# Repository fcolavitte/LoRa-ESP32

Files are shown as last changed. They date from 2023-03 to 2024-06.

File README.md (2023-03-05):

# LoRa-ESP32
Proyecto de comunicación unidireccional de USB a LoRa para pruebas de comunicación con satelites LEO para la empresa Satellogic.
El dispositivo toma datos por Wi-Fi y USB y envía mensajes por módulo LoRa E22 a satélites LEO.

El proyecto cuenta con una interfaz de usuario por USB con un menu interactivo por medio de los números del teclado.
La interfaz USB también admite comandos específicos.

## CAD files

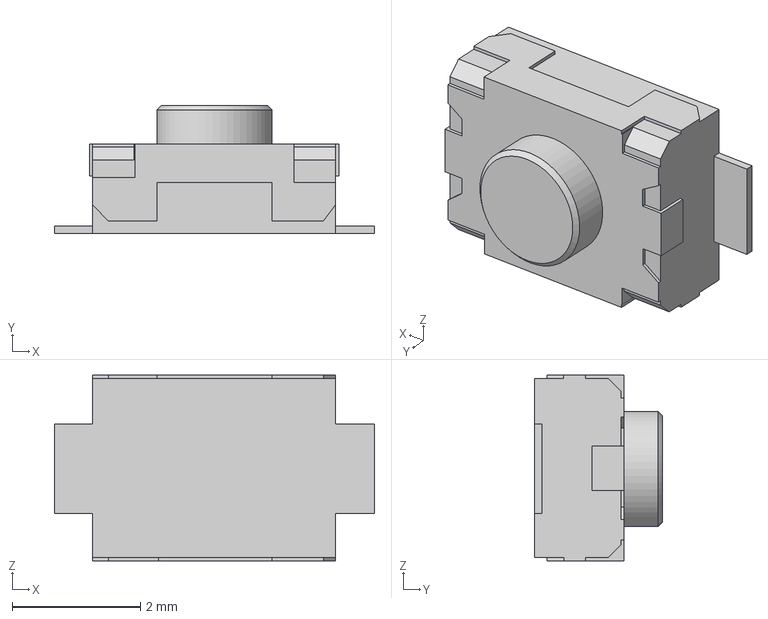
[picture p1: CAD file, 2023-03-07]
Hardware/PCB_Satellogic_2/Componentes STP/smd push button.step
5.00 x 2.00 x 2.90 mm

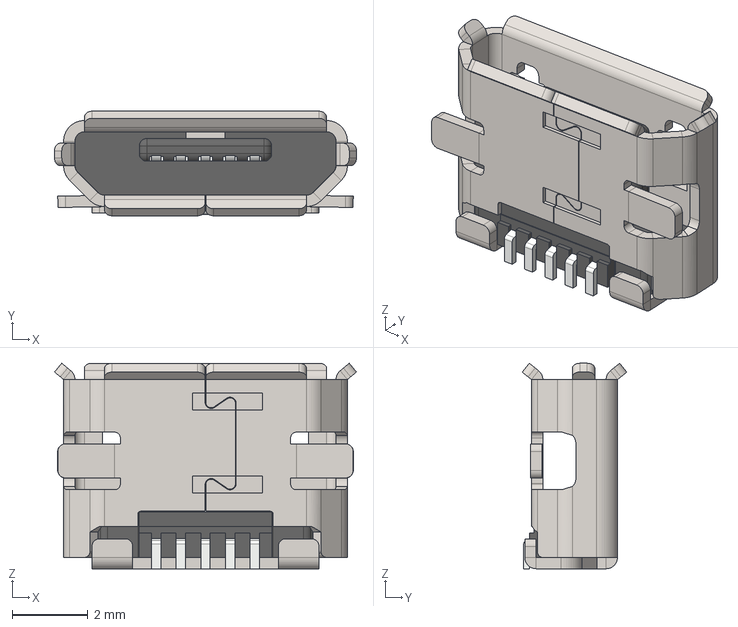
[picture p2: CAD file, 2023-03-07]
Hardware/PCB_Satellogic_2/Componentes STP/micro_USB.STEP
7.98 x 2.76 x 5.43 mm

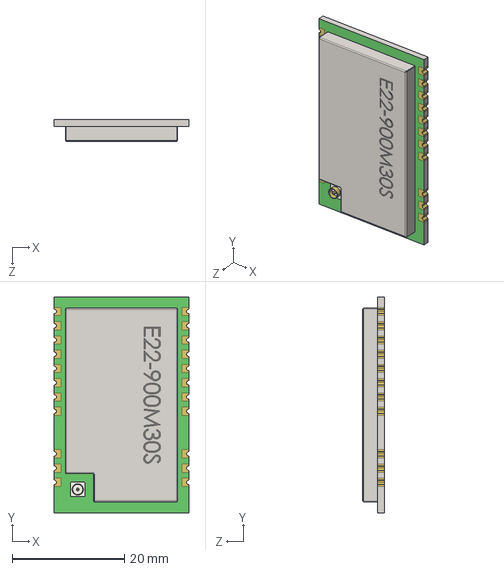
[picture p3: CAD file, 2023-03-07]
Hardware/PCB_Satellogic_2/Componentes STP/E22-900M30S.STEP
24.0 x 38.5 x 3.88 mm

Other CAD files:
Hardware/PCB_Satellogic_2/Componentes STP/E22-900M30S.SLDPRT

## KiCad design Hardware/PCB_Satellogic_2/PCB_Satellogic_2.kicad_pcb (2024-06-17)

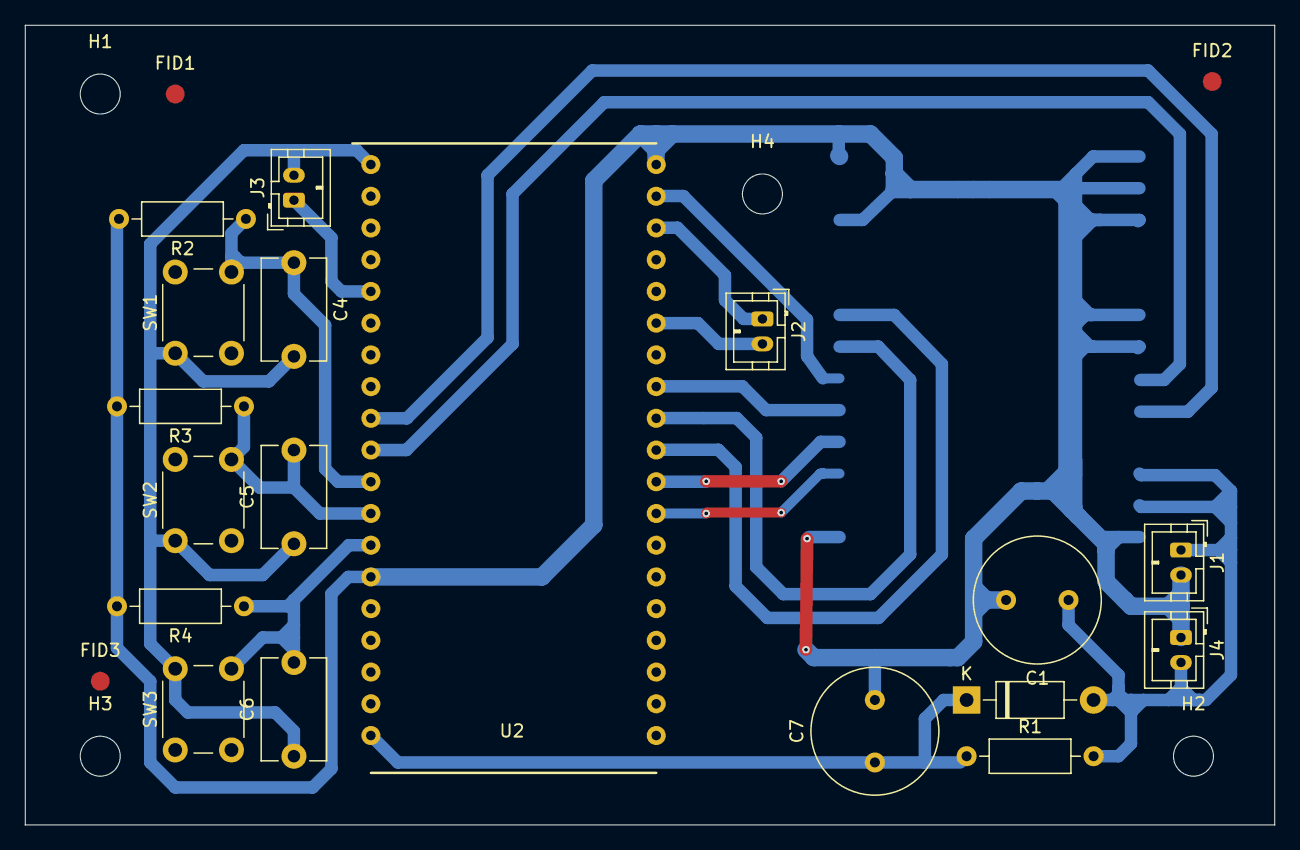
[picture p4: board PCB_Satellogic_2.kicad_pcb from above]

Board: 2 copper layers, 100.0 x 64.0 mm, 26 parts (1 on the bottom side), 18 nets.

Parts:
C1: 470uF; C_Radial_D10.0mm_H16.0mm_P5.00mm
C4, C5, C6: 10nF; C_Disc_D8.0mm_W5.0mm_P7.50mm
C7: 4.7uF; C_Radial_D10.0mm_H16.0mm_P5.00mm
D1: 1N5819; D_DO-41_SOD81_P10.16mm_Horizontal
FID1, FID2, FID3: Fiducial; Fiducial_1.5mm_Mask3mm
H1, H2, H3, H4: MountingHole; MountingHole_3.2mm_M3
J1: 5V_out; JST_PH_B2B-PH-K_1x02_P2.00mm_Vertical
J2: I2C; JST_PH_B2B-PH-K_1x02_P2.00mm_Vertical
J3: ADC; JST_PH_B2B-PH-K_1x02_P2.00mm_Vertical
J4: 5V_in; JST_PH_B2B-PH-K_1x02_P2.00mm_Vertical
R1: 100R; R_Axial_DIN0207_L6.3mm_D2.5mm_P10.16mm_Horizontal
R2, R3, R4: 2k2; R_Axial_DIN0207_L6.3mm_D2.5mm_P10.16mm_Horizontal
SW1: SetRXMode; SW_PUSH_6mm_H4.3mm
SW2: TX; SW_PUSH_6mm_H4.3mm
SW3: SetWiFiMode; SW_PUSH_6mm_H4.3mm
U1: E22-900M30S_LoRa; E22-900M30S_LoRa_smd
U2: Node-MCU_ESP32_38PINES; Node-MCU_ESP32_38PINES_THT_offset

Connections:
/3v3: C4.2, C5.1, C6.1, J3.2, SW1.1, SW2.1, SW3.1, U2.1 (3.3V)
/5V: C1.1, D1.2 (A), J1.1, J4.2, R1.2, U1.9 (Vcc), U1.10 (Vcc)
/ADC: J3.1, U2.5 (GPIO34)
/BUSY: U1.14 (BUSY), U2.27 (Rx2-GPIO16)
/MISO: U1.16 (MISO), U2.31 (MISO-GPIO19)
/MOSI: U1.17 (MOSI), U2.37 (MOSI-GPIO23)
/NSS: U1.19 (NSS), U2.29 (CS0-GPIO5)
/RST_E22: U1.15 (NRST), U2.28 (Tx2-GPIO17)
/RXEN: U1.6 (RXEN), U2.10 (GPIO26)
/SCK: U1.18 (SCK), U2.30 (CLK-GPIO18)
/SCL: J2.1, U2.36 (GPIO22)
/SDA: J2.2, U2.33 (GPIO21)
/SetRxMode: C4.1, R2.1, SW1.2, U2.11 (GPIO27)
/SetWiFiMode: C6.2, R4.1, SW3.2, U2.13 (GPIO12)
/TX: C5.2, R3.1, SW2.2, U2.12 (GPIO14)
/TXEN: U1.7 (TXEN), U2.9 (GPIO25)
GND: C1.2, C7.2, J1.2, J4.1, R2.2, R3.2, R4.2, U1.1 (GND), U1.2 (GND), U1.3 (GND), U1.4 (GND), U1.5 (GND), U1.11 (GND), U1.12 (GND), U1.20 (GND), U1.22 (GND), U2.14 (GND), U2.38 (GND)
unnamed: C7.1, D1.1 (K), R1.1, U2.19 (Vin)

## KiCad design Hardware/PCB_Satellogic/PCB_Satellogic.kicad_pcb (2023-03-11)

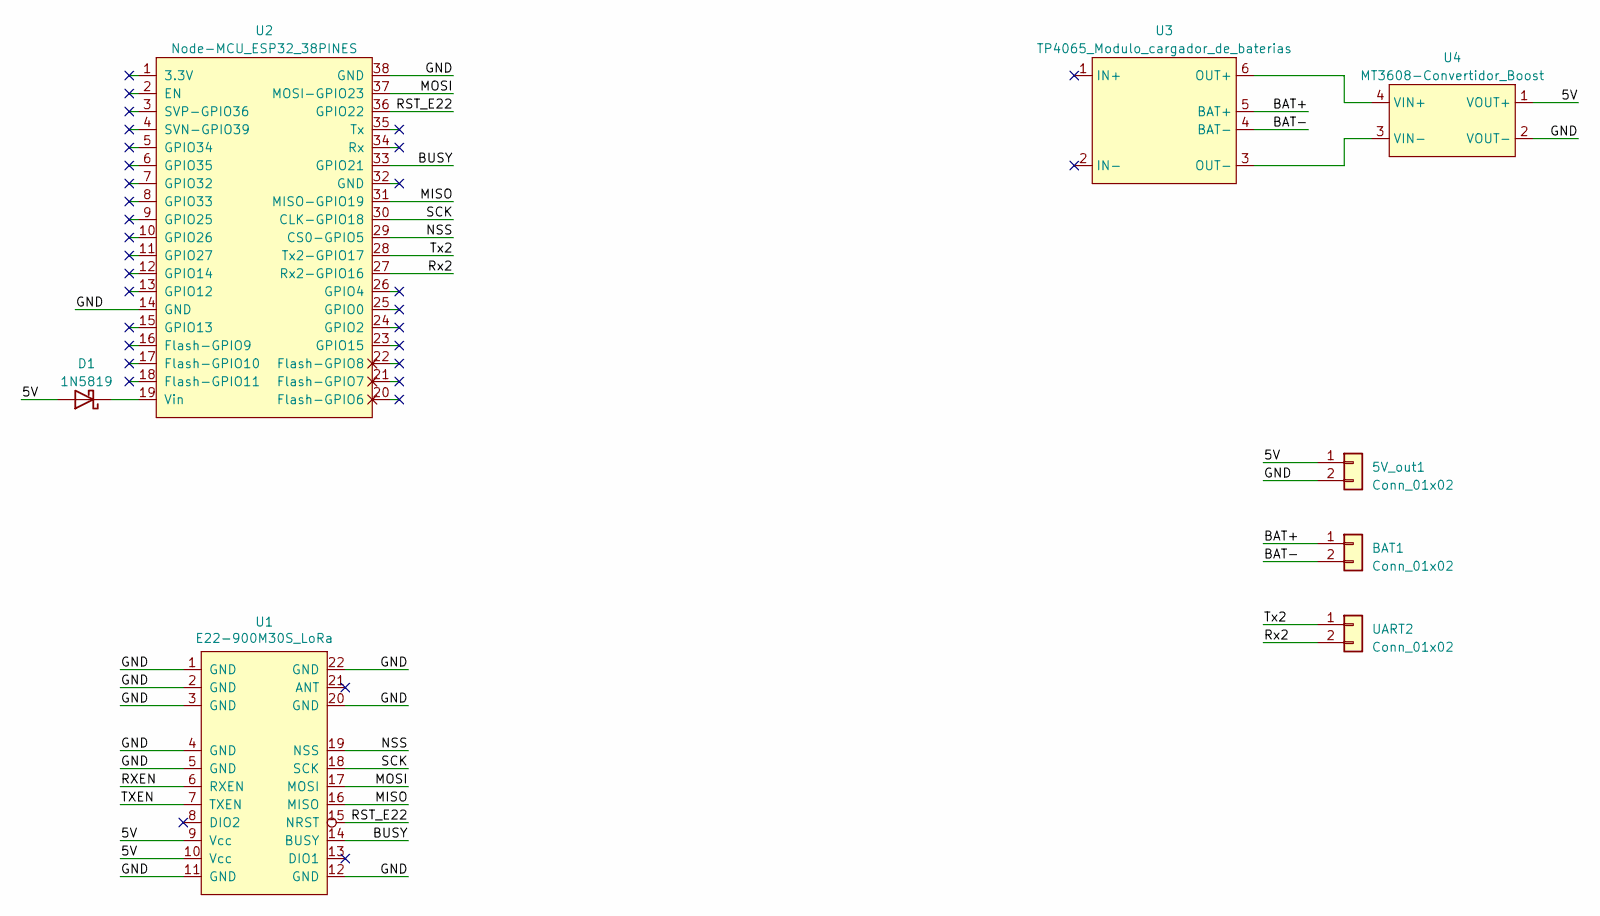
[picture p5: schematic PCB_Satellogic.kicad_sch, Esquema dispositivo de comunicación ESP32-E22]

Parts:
5V_out1: Conn_01x02; JST_PH_B2B-PH-K_1x02_P2.00mm_Vertical
BAT1: Conn_01x02; JST_PH_B2B-PH-K_1x02_P2.00mm_Vertical
D1: 1N5819; D_DO-41_SOD81_P10.16mm_Horizontal
U1: E22-900M30S_LoRa; E22-900M30S_LoRa_smd
U2: Node-MCU_ESP32_38PINES; Node-MCU_ESP32_38PINES_THT_offset
U3: TP4065_Modulo_cargador_de_baterias; TP4056 - Módulo de carga de batería
U4: MT3608-Convertidor_Boost
UART2: Conn_01x02; JST_PH_B2B-PH-K_1x02_P2.00mm_Vertical

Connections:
/5V: 5V_out1.1, D1.2 (A), U1.9 (Vcc), U1.10 (Vcc), U4.1 (VOUT+)
/BAT+: BAT1.1, U3.5 (BAT+)
/BAT-: BAT1.2, U3.4 (BAT-)
/BUSY: U1.14 (BUSY), U2.33 (GPIO21)
/GND: 5V_out1.2, U1.1 (GND), U1.2 (GND), U1.3 (GND), U1.4 (GND), U1.5 (GND), U1.11 (GND), U1.12 (GND), U1.20 (GND), U1.22 (GND), U2.14 (GND), U2.38 (GND), U4.2 (VOUT-)
/MISO: U1.16 (MISO), U2.31 (MISO-GPIO19)
/MOSI: U1.17 (MOSI), U2.37 (MOSI-GPIO23)
/NSS: U1.19 (NSS), U2.29 (CS0-GPIO5)
/RST_E22: U1.15 (NRST), U2.36 (GPIO22)
/RXEN: U1.6 (RXEN)
/Rx2: U2.27 (Rx2-GPIO16), UART2.2
/SCK: U1.18 (SCK), U2.30 (CLK-GPIO18)
/TXEN: U1.7 (TXEN)
/Tx2: U2.28 (Tx2-GPIO17), UART2.1
unnamed: D1.1 (K), U2.19 (Vin)
unnamed: U3.6 (OUT+), U4.4 (VIN+)
unnamed: U3.3 (OUT-), U4.3 (VIN-)

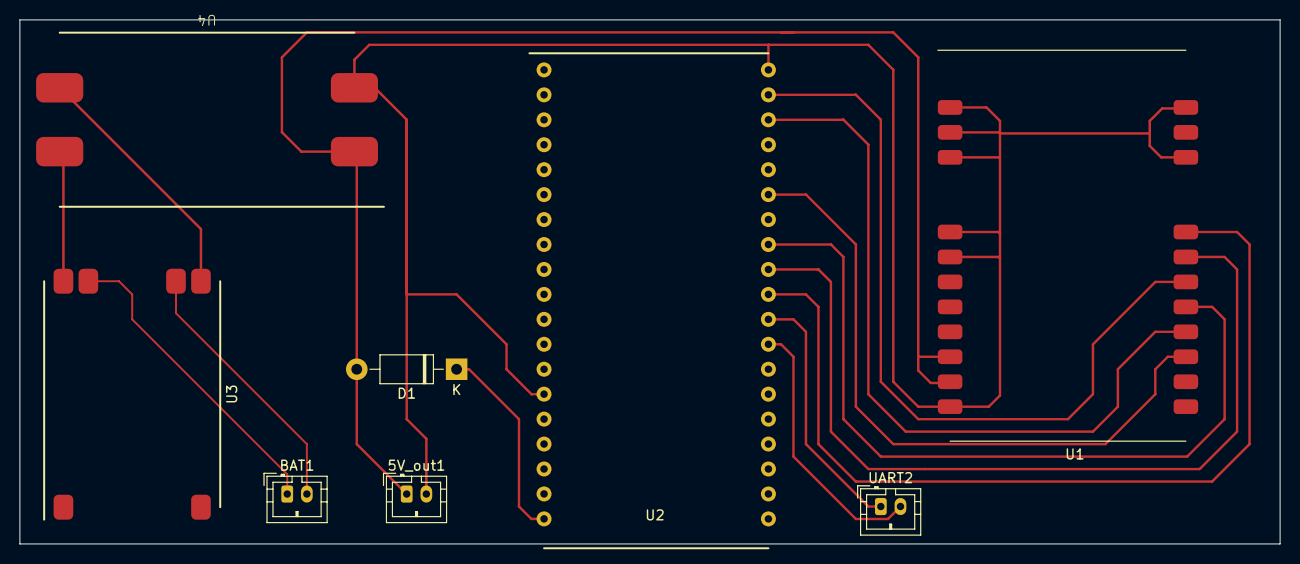
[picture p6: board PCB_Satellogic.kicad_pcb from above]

Board: 2 copper layers, 128.3 x 53.3 mm, 8 parts (0 on the bottom side), 15 nets.

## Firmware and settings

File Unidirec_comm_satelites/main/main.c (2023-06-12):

/*
 * @file   : main.c
 * @date   : Feb 17, 2023
 * @author : Colavitte Facundo G. <facundocolavitte@gmail.com>
 * @version	v1.0.0
 */

/********************** inclusions *******************************************/

#include "MEF.h"
#include "API_E22.h"
#include <freertos/FreeRTOS.h>
#include <freertos/task.h>
#include "E22_test_.h"

/********************** macros and definitions *******************************/

#define test_E22 0

/********************** internal data declaration ****************************/

/********************** internal functions declaration ***********************/

/********************** internal data definition *****************************/

/********************** external data definition *****************************/

/********************** internal functions definition ************************/

/********************** external functions definition ************************/

#if test_E22 == 0
void app_main(void) {
	driver_E22_init();
	start_MEF();
	while(1){
		update_MEF();
        vTaskDelay(10/ portTICK_PERIOD_MS);
	}
}
#endif






#if test_E22 == 1

void app_main(void) {
	start_MEF();
	driver_E22_init();

	while(1){
		/* Test Driver E22 */
		test_driver_E22_read_write_buffer_1byte();
	    test_driver_E22_read_write_buffer_2bytes();
        vTaskDelay(10000/ portTICK_PERIOD_MS);
	}
}
#endif

/********************** end of file ******************************************/

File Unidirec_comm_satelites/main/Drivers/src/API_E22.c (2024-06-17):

/*
 * @file   : API_E22.c
 * @date   : Mar 11, 2023
 * @author : Colavitte Facundo G. <facundocolavitte@gmail.com>
 * @version	v1.0.0
 */

#include "API_E22.h"
#include <stdint.h>
#include <stdbool.h>
#include <freertos/FreeRTOS.h>
#include <freertos/task.h>
#include <string.h>

/********************** inclusions *******************************************/

/********************** macros and definitions *******************************/

/********************** internal data declaration ****************************/

struct config_E22_s{
	uint16_t PreambleLength;
	bool Header_is_fixed_length;
	uint32_t frec_deseada_MHz;
};
struct config_E22_s config_E22 = {
		.PreambleLength = 12,
		.Header_is_fixed_length = 1,
		.frec_deseada_MHz = 915
};

/********************** internal functions declaration ***********************/

/********************** external functions declaration ***********************/

extern void driver_HAL_spi_init(void);
extern uint8_t driver_HAL_transaction(uint8_t *tx_buffer, uint8_t tx_length, uint8_t *rx_buffer, uint8_t rx_length);
extern void driver_HAL_gpio_init(uint8_t GPIO_num, bool GPIO_is_input);
extern void driver_HAL_GPIO_write(uint8_t GPIO, bool state);
extern bool driver_HAL_GPIO_read(uint8_t GPIO);
extern void driver_HAL_set_eneable_transaction_view(bool eneable);
extern bool driver_HAL_get_eneable_transaction_view(void);

/********************** internal data definition *****************************/

/********************** external data definition *****************************/

/********************** internal functions definition ************************/

/********************** external functions definition ************************/

void driver_E22_init(void) {
	driver_HAL_spi_init();
	driver_HAL_gpio_init(GPIO_E22_BUSY, INPUT);
	driver_HAL_gpio_init(GPIO_E22_NRST, OUTPUT);
	driver_HAL_gpio_init(GPIO_TX_ENABLE, OUTPUT);
	driver_HAL_gpio_init(GPIO_RX_ENABLE, OUTPUT);

	/* Cargar estados iniciales de los pines */
	driver_HAL_GPIO_write(GPIO_E22_NRST, HIGH);
	driver_HAL_GPIO_write(GPIO_TX_ENABLE, LOW);
	driver_HAL_GPIO_write(GPIO_RX_ENABLE, LOW);
}


void driver_E22_reset(void) {
	driver_HAL_GPIO_write(GPIO_E22_NRST, LOW);
    vTaskDelay(100);
	driver_HAL_GPIO_write(GPIO_E22_NRST, HIGH);
    vTaskDelay(100);
	driver_E22_set_standBy();
}


void driver_E22_write_in_buffer(uint8_t offset, uint8_t* tx_buffer, uint8_t tx_length) {
	if(MAX_SIZE_SPI_BUFFERS - 2 < tx_length) {
		tx_length = MAX_SIZE_SPI_BUFFERS - 2;
	}
	if(driver_HAL_GPIO_read(GPIO_E22_BUSY)) {
		vTaskDelay(1);
	}
	uint8_t MOSI_buffer[MAX_SIZE_SPI_BUFFERS] = {};
	MOSI_buffer[0] = OPCODE_WRITEBUFFER;
	MOSI_buffer[1] = offset;
	memcpy(&(MOSI_buffer[2]), tx_buffer, tx_length);
	driver_HAL_transaction(MOSI_buffer, tx_length+2, NULL, 0);
    vTaskDelay(1);
}


void driver_E22_read_from_buffer(uint8_t offset, uint8_t* rx_buffer, uint8_t rx_length) {
	if(MAX_SIZE_SPI_BUFFERS - 3 < rx_length) {
		rx_length = MAX_SIZE_SPI_BUFFERS - 3;
	}
	if(driver_HAL_GPIO_read(GPIO_E22_BUSY)) {
		vTaskDelay(1);
	}
	uint8_t MOSI_buffer[MAX_SIZE_SPI_BUFFERS] = {};
	MOSI_buffer[0] = OPCODE_READBUFFER;
	MOSI_buffer[1] = offset;
	MOSI_buffer[2] = NOP;
	driver_HAL_transaction(MOSI_buffer, 3, rx_buffer, rx_length);
    vTaskDelay(1);
}

void driver_E22_clear_buffer(uint8_t offset, uint8_t length, uint8_t characters) {
	if(driver_HAL_GPIO_read(GPIO_E22_BUSY)) {
		vTaskDelay(1);
	}
	if (offset < 255) {
		uint8_t _length = length;
		if(length > MAX_SIZE_SPI_BUFFERS-2){
			_length = length%(MAX_SIZE_SPI_BUFFERS-2);
		}
		uint8_t MOSI_buffer[MAX_SIZE_SPI_BUFFERS] = {};
		for(uint8_t i = 0; i <= length/(MAX_SIZE_SPI_BUFFERS-2); i++){
			for(int i = 0; i<MAX_SIZE_SPI_BUFFERS;i++){
				MOSI_buffer[i] = characters;
			}
			MOSI_buffer[0] = OPCODE_WRITEBUFFER;
			MOSI_buffer[1] = offset + i*(MAX_SIZE_SPI_BUFFERS-2);
			if(length/(MAX_SIZE_SPI_BUFFERS-2) == i){
				driver_HAL_transaction(MOSI_buffer, _length+2, NULL, 0);
    			vTaskDelay(1);
			} else {
				driver_HAL_transaction(MOSI_buffer, MAX_SIZE_SPI_BUFFERS, NULL, 0);
    			vTaskDelay(1);
			}
		}
	}
}

void driver_E22_write_in_registro(uint8_t *address, uint8_t* tx_buffer, uint8_t tx_length) {
	if(MAX_SIZE_SPI_BUFFERS - 3 < tx_length) {
		tx_length = MAX_SIZE_SPI_BUFFERS - 3;
	}
	if(driver_HAL_GPIO_read(GPIO_E22_BUSY)) {
		vTaskDelay(1);
	}
	uint8_t MOSI_buffer[MAX_SIZE_SPI_BUFFERS] = {};
	MOSI_buffer[0] = OPCODE_WRITEREGISTER;
	MOSI_buffer[1] = address[1];
	MOSI_buffer[2] = address[0];
	memcpy(&(MOSI_buffer[3]), tx_buffer, tx_length);
	driver_HAL_transaction(MOSI_buffer, tx_length+3, NULL, 0);
}


void driver_E22_read_from_registro(uint8_t *address, uint8_t* rx_buffer, uint8_t rx_length) {
	if(MAX_SIZE_SPI_BUFFERS - 4 < rx_length) {
		rx_length = MAX_SIZE_SPI_BUFFERS - 4;
	}
	if(driver_HAL_GPIO_read(GPIO_E22_BUSY)) {
		vTaskDelay(1);
	}
	uint8_t MOSI_buffer[MAX_SIZE_SPI_BUFFERS] = {};
	MOSI_buffer[0] = OPCODE_READREGISTER;
	MOSI_buffer[1] = address[1];
	MOSI_buffer[2] = address[0];
	MOSI_buffer[3] = NOP;
	driver_HAL_transaction(MOSI_buffer, 4, rx_buffer, rx_length);
}

void driver_E22_set_standBy(void){
	uint8_t MOSI_buffer[2] = {};
	MOSI_buffer[0] = OPCODE_SETSTANDBY;
	MOSI_buffer[1] = 0x00;
	driver_HAL_transaction(MOSI_buffer, 2, NULL, 0);
	vTaskDelay(1);
}

void driver_E22_GetRxBufferStatus(uint8_t* PayloadLengthRx, uint8_t* RxBufferPointer) {
	if(driver_HAL_GPIO_read(GPIO_E22_BUSY)) {
		vTaskDelay(1);
	}
	uint8_t MISO_buffer[2] = {};
	uint8_t MOSI_buffer[2] = {};
	MOSI_buffer[0] = OPCODE_GetRxBufferStatus;
	MOSI_buffer[1] = NOP;
	driver_HAL_transaction(MOSI_buffer, 2, MISO_buffer, 2);
	*PayloadLengthRx = MISO_buffer[0];
	*RxBufferPointer = MISO_buffer[1];
}


void driver_E22_SetBufferBaseAddress(uint8_t tx_base_adress, uint8_t rx_base_adress) {
	if(driver_HAL_GPIO_read(GPIO_E22_BUSY)) {
		vTaskDelay(1);
	}
	uint8_t MOSI_buffer[3] = {};
	MOSI_buffer[0] = OPCODE_SetBufferBaseAddress;
	MOSI_buffer[1] = tx_base_adress;
	MOSI_buffer[2] = rx_base_adress;
	driver_HAL_transaction(MOSI_buffer, 3, NULL, 0);
    vTaskDelay(1);
}


void driver_E22_SetTx_poner_modulo_en_modo_tx(uint32_t timeout) {
	if(timeout > 0xFFFFFF) {
		timeout = 0xFFFFFF;
	}
	if(driver_HAL_GPIO_read(GPIO_E22_BUSY)) {
		vTaskDelay(1);
	}
	//Pasaje de milisegundos al valor esperado por el E22
	timeout = timeout<<6;
	uint8_t MOSI_buffer[4] = {};
	MOSI_buffer[0] = OPCODE_SET_TX_MODE;
	MOSI_buffer[1] = (uint8_t)(timeout >> 16);
	MOSI_buffer[2] = (uint8_t)(timeout >> 8);
	MOSI_buffer[3] = (uint8_t)(timeout >> 0);
	driver_HAL_transaction(MOSI_buffer, 4, NULL, 0);
	vTaskDelay(10);
}
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

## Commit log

2023-03-07 Introducción HW
    [E22-900M30S.SLDPRT, E22-900M30S.STEP, PCB_Satellogic.kicad_pcb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]
2023-05-20 Regularizacion del formato de archivos
2023-05-22 Redacción de E22_port_ y comienzo de redacción del driver
2023-05-24 avances driver E22 y test de driver
2023-06-12 Modificación de API_time para usar RTC interno
2023-06-12 Correcciones menores en include de main.c
2023-06-12 Se verificó que el comando > escriba en ringbuffer y eliminó menú USB Firebase
2023-06-15 Se terminó API_time y se terminó de integrar con API_USB
2023-06-17 Corrección de bug al cargar fecha despues de las 21:00:00hs. Implementación del menu config_E22
    [API_E22.c]
2023-06-17 SE implementó MEF para envío de mensajes programados y beacon y se integró con interfaz USB
2023-06-17 Se integró la configuración vía Wi-Fi con la USB
2023-06-17 Se agregó posibilidad de modificar SSID y PASS a la que conectarse guardada en memoria no volatil. Se agregó reconexión automática a Wi-Fi.
2023-06-17 Se agregó comandos de reinicio y reconexión a Wi-Fi
2023-06-18 Se agregó función para poner al E22 en modo Rx para hacer la prueba entre dos dispositivos en tierra.
2024-02-25 adición ; en saltos de línea antes de declaración de variables
2024-03-03 Se agregó palabra de sinc
2024-03-04 Se corrigieron detalles menores
    [API_E22.c]
2024-05-31 Se agregaron standbyte y DIO3, ya emite y visualiza el SDR
2024-06-09 Se hardcodeó transacciones SPI
2024-06-10 Se agregó función para ver registros
    [PCB_Satellogic.kicad_sch]
2024-06-14 Se emprolijó codigo de send y recibe mesage
2024-06-16 se corrijió largo de mensaje a enviar variable y se acomodaron comentarios de código
2024-06-17 Diseño PCB 2 con I2C para pantalla OLED y pulsadores
    [E22-900M30S.SLDPRT, E22-900M30S.STEP, PCB_Satellogic.kicad_sch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]
